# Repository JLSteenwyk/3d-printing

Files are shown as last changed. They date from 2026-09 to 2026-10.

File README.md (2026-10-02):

# 3D printing projects

Source models, printable exports, and build notes for projects printed on a
Bambu Lab P2S. Dimensions are in millimeters. Each project lives in its own
directory so materials, revisions, and instructions stay together.

| Project | Material | Status |
| --- | --- | --- |
| [01 — Olive Lantern](projects/01-olive-lantern/) | Bambu PETG Translucent, Olive | Prototype; physical fit and print validation pending |
| [02 — Organic Lantern TriLamp](projects/02-trilamp-desert-tan/) | PLA Matte, Desert Tan / grey-blue | Bowed shade, rounded cap, and source-based local full-set build |
| [03 — Narrow Flutes Tray Lamp](projects/03-narrow-flutes-tray-lamp/) | Translucent olive PETG / desert tan PLA trim | V2 one-piece body prototype; tray fit, socket adapter, slicing and heat tests pending |

Repository: https://github.com/JLSteenwyk/3d-printing

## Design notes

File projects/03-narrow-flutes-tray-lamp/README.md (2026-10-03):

# Narrow Flutes Tray Lamp — V2

A Bauhaus-inspired, translucent olive PETG lamp with a snug recessed receiver
for an unmodified Nordik leather valet tray. The olive body, tray ledge and lower
frame print as one connected part; desert tan PLA trim prints separately.
One horizontal Govee H6008 A19/E26 bulb is reserved inside the body.

**Mechanical prototype:** the socket adapter and strain relief are unfinished.
The R27 corner coupon and complete tray rim have been physically tested and
accepted by the user. Slicing, support-free printing, strength and heat behavior
still need validation. Socket mount and cord restraint remain unfinished.

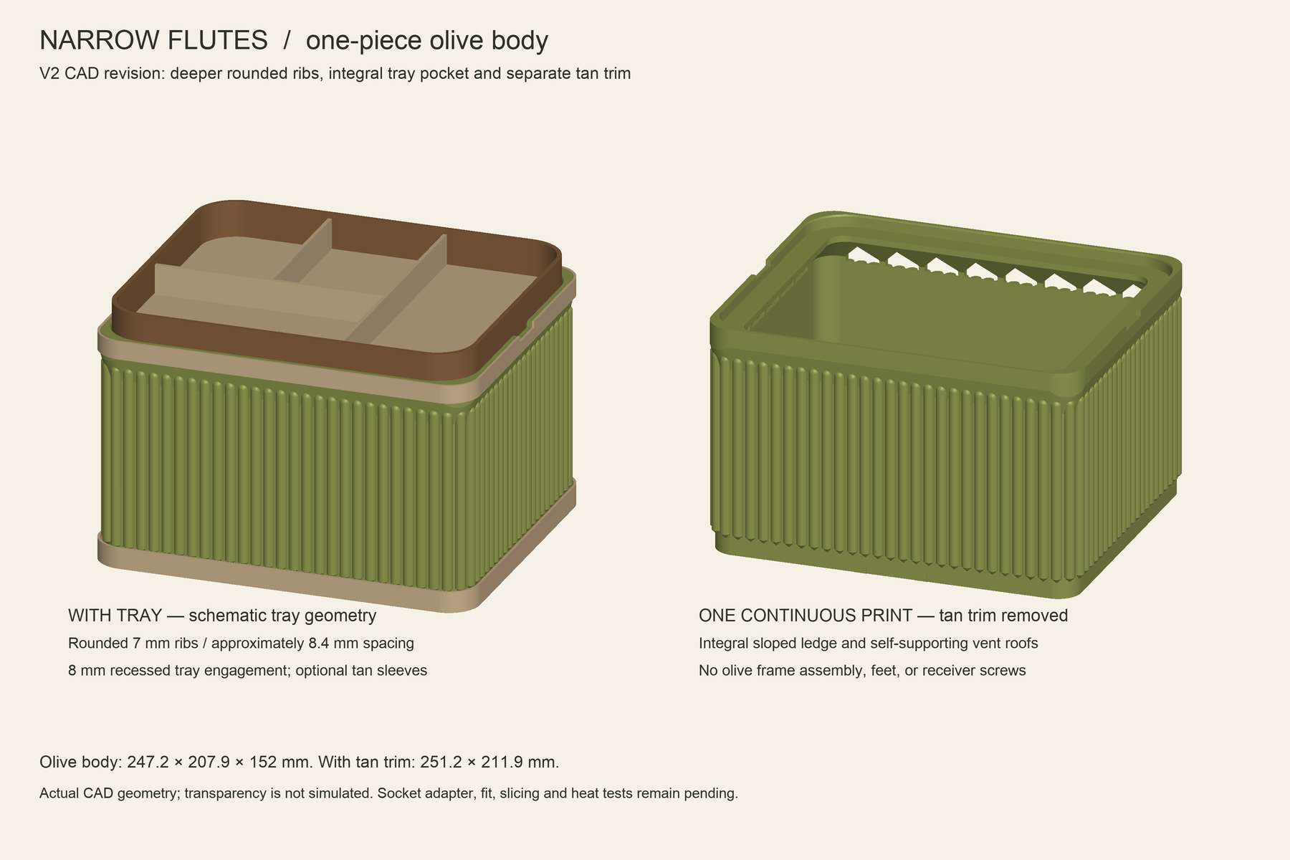
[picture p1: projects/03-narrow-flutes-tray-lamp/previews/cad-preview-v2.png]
Actual CAD geometry, with a schematic tray


## Downloads

| Part | Material | Purpose |
| --- | --- | --- |
| [Corner coupon](models/tray_corner_coupon.stl) | PETG | Accepted R27 corner shape; optional repeat check |
| [Complete fit-test rim](models/tray_fit_test_rim.stl) | PETG | Confirm full length, width and grip-pad fit |
| [One-piece olive body](models/olive_body_one_piece_PETG.stl) | Translucent olive PETG | Integral diffuser, frame and tray receiver |
| [Base trim](models/tan_base_trim_PLA.stl) | Desert tan PLA | Separate cosmetic sleeve |
| [Top trim](models/tan_top_trim_PLA.stl) | Desert tan PLA | Separate cosmetic sleeve |

STLs use millimeters and are placed flat/upright with minimum Z at zero.
The body uses ordinary printing mode, not vase mode. Sloped ledge supports and
45-degree vent roofs are intended to avoid trapped supports, but a connected
mesh is not proof of a successful support-free print. No verified P2S 3MF or
G-code is included.

## Dimensions and fit

| Feature | Dimension |
| --- | --- |
| Provided tray | 240.03 × 200.66 × 25.40 mm; 371.4 g before contents |
| Olive body | 247.23 × 207.86 × 152 mm |
| Footprint with tan trim | 251.23 × 211.86 mm |
| Tray pocket | 241.23 × 201.86 mm; 8 mm deep |
| Rigid clearance | 0.6 mm per side; adjustable compressible grip pads |
| Height with inserted tray | 169.4 mm |
| Rib profile | Rounded 7 mm-wide ribs, ~8.4 mm pitch, 3.4 mm relief |

The tray corner radius is **27 mm**, selected through a printed coupon fit test
and accepted on October 2, 2026. It is a fitted model value, not a direct radius
measurement. The exterior corner radius remains 18.6 mm, as on that coupon.
The complete rim and lamp now use this accepted pocket shape. The complete rim was also accepted by the user on October 2, 2026. The tray lifts out deliberately;
the receiver restricts sideways movement without a positive upward latch.

The 251.23 mm-wide trim leaves only about 2.38 mm per edge on the P2S's nominal
256 mm build area. Check plate placement and brim width in Bambu Studio.

## Regenerate

Tested with Python 3.12 and the versions in [requirements.txt](requirements.txt).
From this project directory:

```sh
python -m venv .venv
source .venv/bin/activate
python -m pip install -r requirements.txt
python src/generate.py
```

Edit [parameters.json](parameters.json) before regenerating. The script writes
the meshes to `models/`, validation to `docs/`, and the CAD preview to `previews/`.
Fonts fall back to a bundled Pillow font if Arial or DejaVu Sans is unavailable.
Some rib geometry, vent positions and mounting features remain fixed prototype
values in the source; review those when changing major dimensions.

To reproduce the optional geometric overhang screening (also regenerates the
models and preview):

```sh
python src/screen_overhang.py
```

## Validation and remaining work

[Mesh report](docs/validation.json): all five designs are single connected,
watertight, consistently wound solids within the nominal 256 mm build envelope.
Tan sleeves do not overlap the olive body. Reserved bulb/socket envelopes do not
intersect the body. Exported STL files were reloaded and checked for watertightness
and exactly two incident faces per edge.

[Overhang screening](docs/overhang-screen.json) compares 0.2 mm-spaced horizontal
sections with the prior section expanded by 0.25 mm. It identifies small local
overhangs; it is **not** toolpath generation or slicer validation.

Before the complete lamp is used:

1. Tray pocket fit is accepted; confirm any added grip pads before use.
2. Select a complete prewired E26 socket/cord assembly and design its adapter,
   retention and strain relief. The current 45 × 45 mm socket allowance is provisional.
3. Inspect and slice the full body in Bambu Studio; verify bridges and print settings.
4. Test the printed receiver with the tray and intended contents, then validate
   temperatures with the chosen bulb and the tray installed.

The H6008 label prohibits totally enclosed luminaires. V2 has intake and exhaust
windows on the rear and left end; acceptable temperatures have not been established.
This incomplete prototype should not be energized before hardware is finalized.

See [detailed design notes](docs/design-notes.txt) for mounting-pad geometry,
materials, fit tests and assembly limitations. The tray in the preview is schematic;
PETG transparency and glow are not simulated.

## References

- [Nordik tray](https://www.amazon.com/dp/B0C9CFWXQK)
- [Govee bulb](https://www.amazon.com/dp/B09B7NQT2K)
- [Manufacturer bulb label](https://fcc.report/FCC-ID/2AQA6-H6008/5384919.pdf)

This project was designed independently and does not include models from the
repository's TriLamp project.

## Socket fit test

The selected assembly is [Zarnicy B0D3TMJPWR](https://www.amazon.com/dp/B0D3TMJPWR).
The existing bulb/socket envelope check still uses the original provisional
45 mm socket allowance; it is not validation of the delivered Zarnicy socket.

Print [socket_hole_fit_gauge_37-41mm.stl](models/socket_hole_fit_gauge_37-41mm.stl)
flat in PETG at 100% scale. Five separate 3 mm thick rings are identified by
edge notches: 1 = 37 mm, 2 = 38 mm, 3 = 39 mm, 4 = 40 mm, 5 = 41 mm.
With the cord unplugged, choose the smallest ring that slides freely over the
external socket threads, then check that the original retaining ring clamps it
against the socket shoulder. Do not force or screw the printed gauge onto threads.
The final bracket depends on this fit result.

See [instructions](fit-revisions/socket/instructions.txt) and
[validation](fit-revisions/socket/validation.json). The generator writes the
gauge STL beside itself; copy it to models/ when regenerating.

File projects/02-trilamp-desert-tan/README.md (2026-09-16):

# TriLamp — Organic Lantern shade and matching cap

A softer replacement for the tall TriLamp shade: gently bowed sides, flowing
shallow waves, varied small openings, and a fine fuzzy finish. Designed for opaque
PLA in Desert Tan or other muted colors, including grey-blue.

**[Current design, cap download, and full-set build instructions](variants/organic-lantern/)**

## What is available here

- Our shade generator, cap design, stand extraction and project-building code.
- The independently designed matching cap, in printable STL and P2S 3MF formats.
- Previews and validation reports for the current design.
- Instructions for creating the full five-part set locally from the original file.

The original **TriLamp by XYZilla** is available on
[MakerWorld, model 772090](https://makerworld.com/en/models/772090).
Download the original stand files there; this public repository does not mirror
them. The source file identifies the Standard Digital File License, which
restricts redistribution of the original models and derivatives. Consequently,
source-derived shade meshes and the full-set 3MF are generated locally and
excluded from Git unless separate publication permission is obtained.

The three original tall-stand components are `TriLampStand.stl`,
`TriLampStand2.stl`, and `TriLampStand3.stl` (plate 6 of the supplied all-variants
project). The local build extracts them without changing their shape, preserving
the original print orientation.

[Previous Soft Spiral version](variants/soft-spiral/) remains available.

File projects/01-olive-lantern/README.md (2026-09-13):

# Olive Lantern

A mid-century modern floor-lamp sleeve: seven softly rounded sections, twelve
shallow vertical flutes, and a fine pebbled olive finish. The repeated forms
reference stacked ceramic lamps and paper lanterns. A removable, beveled saucer
cap finishes the top while leaving a central ventilation opening. Translucent PETG and fuzzy
skin should soften the LEDs; actual diffusion and color need a print trial.

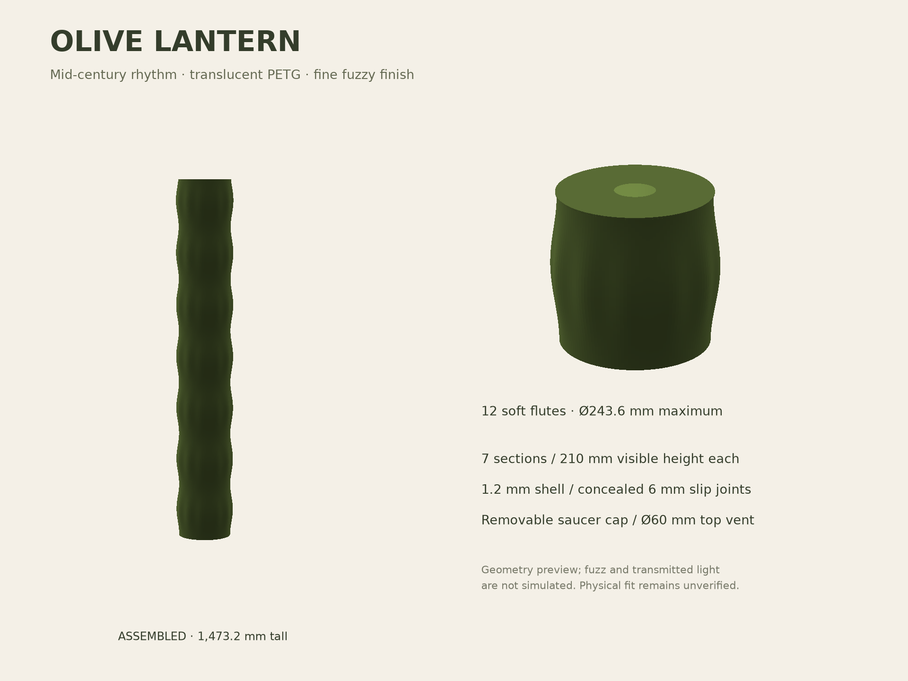
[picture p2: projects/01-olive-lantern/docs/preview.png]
Geometry preview


**Prototype status:** printable meshes are supplied, but physical fit, heat,
stability, and diffusion have not been tested. The full-height sleeve is the
initial design assumption; dimensions are based on the online sources below.

## Lamp and fit

The [linked Amazon listing](https://www.amazon.com/dp/B0BLSGHRXB?th=1) identifies
a Govee H6076 RGBIC floor lamp, with nominal dimensions 7.9 × 7.9 × 53.7 inches
(200.7 × 200.7 × 1364 mm). This is a freestanding sleeve around that lamp, with
its own bottom edge resting on the floor. There is no socket fitting, pole
clamp, or load on the LED column. Govee's [H6076 manual](https://m.media-amazon.com/images/I/B1zVyXg1UkL.pdf)
shows a cable leaving the base, followed by an inline controller and separate
power adapter. The rear arch admits the cable from below, so neither the
controller nor the adapter needs to pass through it. Their dimensions therefore
do not constrain the shade's diameter. The manual does not dimension the cable
exit or strain relief; the arch is a design allowance, not a measured fit.

An [H6076 product information sheet](https://maxelektro.pl/storage/file/pimcore_import/2023/10/6/c3b5da00f8b2dd766408e5ee16213a8f/lampa-led-govee-h6076-karta-informacyjna-produktu.pdf)
also reports 200 × 200 × 1410 mm. Rather than assume these listings describe
identical revisions, the shade covers the taller published envelope too, with
60 mm of headroom. For the exact linked 53.7-inch silver variant, headroom is
about 106 mm. Sources researched September 12, 2026.

| Dimension | Design |
| --- | --- |
| Assembled height | 1473.2 mm with cap; 1470 mm without |
| Maximum diameter | 243.6 mm, before fuzz |
| Visible section height | 210 mm |
| Base / middle print height | 216 mm, including collar |
| Top print height | 210 mm, no protruding collar |
| Separate cap | Ø224 × 9.2 mm in print orientation; adds 3.2 mm when seated |
| Cap vent / roof | Ø60 mm central opening / 1.6 mm roof |
| Shell thickness | 1.2 mm radial; approximately three extrusion lines |
| Bottom opening diameter | 217.6 mm |
| Minimum passage diameter, inside collars | 214.5 mm |
| Male collar outside diameter | 216.9 mm |
| Joint clearance | 0.70 mm diametral / 0.35 mm radial |
| Collar engagement | 6 mm |
| Rear cable arch | 10 mm high, approximately 21 mm wide at floor; 8 mm flat crown |

The 214.5 mm minimum passage gives approximately 6.9 mm radial clearance
around the linked nominal 200.7 mm base when centered. The shade is located
concentrically around that base, not around the off-center column. Use the short
fit ring to verify the as-printed clearance before making seven large parts.
Keep the inline controller and adapter outside the shade, with the flexible
cord laid through the open-bottom arch. If the cable exit prevents the bottom
rim from sitting flat, enlarge the arch parameter before printing the full set;
do not trap or sharply bend the cord.

## Files and print quantities

| STL | Quantity | Purpose |
| --- | --- | --- |
| [fit_male.stl](models/fit_male.stl) | 1 first | Short ring with the actual minimum bore and male collar |
| [fit_female.stl](models/fit_female.stl) | 1 first | Mating clearance check |
| [base.stl](models/base.stl) | 1 | Bottom section with rear cable arch |
| [middle.stl](models/middle.stl) | 5 | Repeated section with top collar |
| [top.stl](models/top.stl) | 1 | Uppermost shade section; receives the cap |
| [cap.stl](models/cap.stl) | 1 | Removable beveled lid with central vent |

Print the rings separately, upright, with no fuzz. Confirm that the female ring
seats on the male shoulder by hand without force and that the male ring clears
the lamp. These simplified rings test nominal joint diameters; the complete
base and one middle section are the next assembly test. Full-size female
openings flare slightly above their bottom edge.

The seven shells contain about 1.30 liters of plastic, roughly **1.7 kg of
PETG** using 1.27 g/cm³ as an estimate, before brims, calibration, and test rings.
Plan for two 1 kg spools; use the slicer's estimate for purchasing and scheduling.
The separate cap adds approximately 85 g before brim and slicer adjustments.

## Top cap

Print [cap.stl](models/cap.stl) **as supplied, broad exterior face on the plate
and locating collar pointing up**. Use the same PETG, 0.20 mm layers, 3 walls,
3 top/bottom layers, and a 3 mm brim. For this part use **100% infill** so the
1.6 mm roof is solid throughout. Supports and vase mode stay off. Its flat
annular face sits on the bed and the beveled edge narrows upward; there is no
large unsupported roof to bridge.

Keep fuzzy skin **off on the cap** for the first print. Its visible flat face
takes the build plate's finish; fuzzy skin does not texture this horizontal
face. A textured plate gives it a complementary texture. The locating collar
and seating annulus must remain smooth for fit.

After printing, flip it over and lower its collar into the existing top section.
It uses the same 0.35 mm radial clearance and 6 mm engagement as the test rings.
The cap is removable and needs no glue; it covers about 92% of the original
opening, leaving a Ø60 mm central vent (approximately 28 cm²). Keep that vent
clear. This opening is a ventilation provision, not verified thermal performance:
repeat the attended lighting trial with the cap fitted. Remove it if heat builds
up. The original upper shade section and other previously generated parts are
compatible without modification.

## Bambu Studio setup

These are proposed starting settings, not a physically qualified print profile.
STLs contain geometry only; they do not contain fuzzy skin or printer settings.

1. Select **Bambu Lab P2S, 0.4 mm nozzle**, and **Bambu PETG Translucent**. Use
   the filament profile's temperatures, cooling, and volumetric flow limit.
   The locally installed Studio 2.8.2.61 P2S preset specifies 250°C first layer,
   245°C subsequent layers, and 6 mm³/s maximum volumetric speed. Keep the
   selected plate's matching bed preset and prepare it for PETG. Dry the spool
   according to Bambu's current material instructions.
2. Begin with 0.20 mm layers, **3 wall loops**, **0% sparse infill**, and 3 top /
   bottom shell layers. The modeled center stays open; top and bottom layers
   only close the thin material rims and shoulder. Keep vase mode **off**.
   Use Arachne wall generation if the fixed-width preview leaves shell gaps.
3. Place **one section per plate**, upright as supplied, at 100% scale. Use a
   3 mm outer brim, supports off, outer wall speed around 40 mm/s, and align
   the seam toward the rear cable opening. Inspect the cable arch's short crown
   bridge on the base trial. Enable neither a prime tower nor smooth timelapse
   features that reserve space or cause unnecessary travel.
4. Set **Fuzzy skin: Contour**, thickness **0.15 mm**, point distance **0.40 mm**.
   Keep **Z=0–14 mm and Z=204 mm to the part top smooth** using height-range
   settings with fuzzy skin disabled. Alternatively paint only the outside
   between those heights in Studio's fuzzy-skin painting tool. The upper smooth
   range includes the collar and shoulder. The bottom smooth range preserves
   the cable arch, first layers, and receiving rim. Use no fuzz on either test
   ring. Inspect the sliced preview to confirm that the inner walls and mating
   surfaces are smooth, especially around the arch.
5. Inspect all layers for a continuous shell, preserved collar, open center,
   and plate clearance before sending a job. A nominal 3 mm brim plus 0.15 mm
   fuzz stays within a 256 mm square, but the selected printer's exclusions,
   purge lines, and slicer placement still need checking.

Print the base first to assess the actual material's light transmission and
texture before making the other six pieces. Fuzzy skin scatters light and may
make the olive look more opaque. Try a warm white lamp setting first; tinted
plastic will alter the apparent RGB colors. For a coarser finish, trial 0.20 mm
thickness and 0.50 mm point spacing on a small sample before changing the set.

## Assembly

Turn off and unplug the lamp. Lower the base section over the column and seat
it on a hard, level floor around the lamp base, with the cable arch at the rear.
Route the cord through the arch without pinching; reconnect only once clearance
is checked. Lower the five middle sections individually over the column, then
the top section. Each receiving rim rests on the previous shoulder; rotate the
flutes and rear seams into alignment. Flip the separately printed cap collar-down
and seat it in the top section; leave the central vent unobstructed.

The slip joints locate the sections but **do not lock them together**. Check
the stack for rocking and use removable clear tape bridging the outside of
each joint for the initial trial. Keep it where it cannot be bumped, and move
it by dismantling it, not by lifting the top. A narrow, tall freestanding shade
needs an actual stability check before regular use; if the intended location
is exposed to knocks, add a measured base restraint before installing it there.

For the first lighting trial, run the actual LED lamp at its brightest intended
setting while attended. Confirm there is an air gap around the column, the cord
is free, and the shade does not soften, distort, or develop a hot spot as it
warms up. PETG temperature resistance is not proof that this assembly is safe.
This design is for the linked LED column, not incandescent or halogen lamps.

## Regeneration and validation

From the repository root:

```bash
python3 projects/01-olive-lantern/src/generate.py
# Optional geometry illustration; requires numpy and matplotlib:
python3 projects/01-olive-lantern/src/preview.py
```

Edit `Parameters` in [src/generate.py](src/generate.py) to change the neck,
wall, flutes, or clearances, then regenerate all parts together. Dimensions in
this README describe the defaults. The height / vertical-step ratio is
constrained to 2 mm to retain the modeled collar taper. Changing the number of
sections affects the preview and required quantity, not the individual STL.

The generator checks nondegenerate triangles, two faces per edge, consistent
winding, positive enclosed material volume, and nominal P2S bounds. Results
are in [docs/mesh-report.json](docs/mesh-report.json). The slicer trial and its
limitations are in [docs/validation.md](docs/validation.md). These checks do not prove
physical fit, stability, thermal performance, or successful printing.

## References

- [Lamp listing](https://www.amazon.com/dp/B0BLSGHRXB?th=1): lamp identification and nominal envelope.
- [Govee H6076](https://us.govee.com/products/govee-rgbicw-smart-corner-floor-lamp): manufacturer's lamp page.
- [P2S manufacturer announcement](https://blog.bambulab.com/the-icon-redefined-meet-the-p2s-a-completely-reengineered-version-of-the-ultra-productive-p1-series/): 256 × 256 × 256 mm build volume.
- [Bambu PETG Translucent](https://us.store.bambulab.com/products/petg-translucent?id=42479468281992): translucent material and Olive color, #748C45.
- Bambu Studio 2.8.2.61 installed BBL profiles: P2S 0.4 mm PETG Translucent temperature and flow settings. The fuzzy values above are design recommendations.

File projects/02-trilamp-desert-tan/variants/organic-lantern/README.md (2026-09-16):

# Organic Lantern — bowed shade and rounded cap

[Color preview](previews/colors.png) · [Cap STL](models/cap.stl) ·
[Cap 3MF](studio/TriLamp_Organic_Lantern_Cap_P2S.3mf)

A warmer revision of Soft Spiral with a fuller middle, gently wandering shallow
waves, and staggered rounded slits of varying lengths. Fine external fuzzy skin
is enabled at 0.12 mm thickness / 0.4 mm point distance, with the fitting bands
kept smooth. Desert Tan and muted grey-blue use the same geometry; the blue
preview is illustrative rather than a matched filament swatch.

## Geometry

- Shade height: 210 mm; unchanged 85 mm end diameter.
- Middle: approximately 95 mm diameter, with a subtle asymmetric contour.
- Wave depth reduced from 0.8 to 0.45 mm; spacing increased from 5.2 to 7 mm.
- 936 rounded slits, nominally 4.6–5.6 mm long and 2.25 mm high before
  tilting to follow the waves, with continuous gently arched roofs.
- Approximate projected opening area: 9,488 mm² versus 9,420 mm² previously.
  This preserves aperture area, not a measured light-output guarantee. Opaque
  filament sends light through the openings; it will not glow like translucent PLA.
- Original keyed mounting geometry retained; both end interfaces remain fixed.
- Removable cap: 85 mm diameter, rounded 1 mm edge radius, 2 mm roof, 4 mm
  locating ring, and twelve curved vents. The previous Soft Spiral cap also fits.

The previews render the actual assembled meshes. Fuzzy skin is applied during
slicing and is not shown in these previews. Physical fit and illumination have
not been tested on a printed prototype.

## Local printable files

The build creates shade-only Desert Tan and grey-blue projects, a cap project,
a three-part original stand project, and a full five-part project on two plates.
Plate 1 holds the shade and cap; plate 2 holds the original tall stand parts.
Projects use Bambu P2S / 0.4 mm nozzle / PLA Matte / 0.2 mm layers / Textured PEI,
with supports disabled. Cap prints exterior face down and locating ring up;
flip it to install. Change the filament preset when using a different material.

## Build from the original

Obtain the original all-variants 3MF from
[TriLamp by XYZilla on MakerWorld](https://makerworld.com/en/models/772090).
The original file's Standard Digital File License restricts redistribution.
Original stands and meshes containing the original mount stay local; this
repository publishes our code, independent cap, and previews.

From the repository root on macOS with Bambu Studio installed:

```sh
python3 -m venv .venv
.venv/bin/pip install numpy trimesh manifold3d scipy networkx shapely matplotlib
.venv/bin/python projects/02-trilamp-desert-tan/variants/organic-lantern/src/build_all.py '/path/to/TriLamp-AllVariants(4).3mf'
```

The build validates the mesh, compares the retained mount against the original,
checks cap interference, exports native Bambu Studio projects, and slices the
complete set. It reports slicer warnings if any occur. Files are written to
this variant's `models/` and `studio/` directories. Use `--studio` to specify
another Bambu Studio executable path.

## Validation of this revision

Both plates sliced successfully in Bambu Studio 2.08.02.61 with supports off
and no plate warnings. Shade + cap: approximately **105 g / 8 h 37 min**.
The complete set including the three original stand parts: approximately
**164 g / 12 h 8 min**. These are slicer estimates, not measured print times.
Meshes are closed solids, the retained mount matches within export precision,
and the cap has no modeled interference with the shade.

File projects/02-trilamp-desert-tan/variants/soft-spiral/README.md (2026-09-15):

# Soft Spiral — tall shade, matching cap, and full local set

[Cap 3MF](studio/TriLamp_Soft_Spiral_Cap_P2S.3mf) ·
[Cap STL](models/cap.stl) · [Cap preview](previews/cap.png) ·
[Shade color preview](previews/colors.png)

Soft Spiral uses rounded horizontal folds and small capsule openings in their
valleys, with fine fuzzy skin for a softer finish. Desert Tan and the illustrative
muted grey-blue preview use the same geometry. The inner keyed mounting recess
is retained from the supplied tall TriLamp shade.

## Complete set

| Part | Availability |
| --- | --- |
| Soft Spiral shade | Generate locally using the original 3MF |
| Matching vented cap | Printable files linked above |
| Original tall stand, `TriLampStand.stl` | Obtain from XYZilla; extracted by the local build |
| Original stand base, `TriLampStand2.stl` | Obtain from XYZilla; extracted by the local build |
| Original collar, `TriLampStand3.stl` | Obtain from XYZilla; extracted by the local build |

The full local project has two plates: shade + cap, then the three stand parts.
All use P2S / standard 0.4 mm nozzle / PLA Matte / Textured PEI settings. The
stand geometry is unmodified; its base is flipped to match the original profile's
printing orientation. Change the stand material preset if printing it in PETG.

### Matching cap

A removable drop-in cap, independently designed for the final Soft Spiral shade:
85 mm maximum diameter, a 2 mm roof, and a 4 mm locating ring. The ring has
approximately **0.34 mm minimum radial clearance** and a tapered entry. Twelve
rounded concentric vents match the softer surface treatment. The cap is retained
by gravity, not a latch. Print exterior face down, then flip to install.

Fuzzy skin is limited to the short roof perimeter; the locating ring stays smooth.
It adds 2 mm to the assembled shade height. Geometry checks find no interference
with the shade. **Cap estimate: 15 g / 42 min.**

### Shade and colors

210 mm tall × 85 mm maximum diameter; 1.2 mm radial body wall. Spiral pitch is
5.2 mm, with 0.8 mm crest-to-valley relief. The 1,120 small openings are
5.6 × 1.6 mm, with rounded ends and offsets between turns. The repeating pattern
has approximately 20% projected open area; light passes through these openings
in opaque filament. Actual light output has not been measured.

Desert Tan display color is #E8DBB7. Grey-blue is **illustrative #6F8491**, not a
matched Bambu swatch. Both generated color files use PLA Matte settings; choose
your actual filament profile, especially for PETG or another material.

## Build the full set locally

Download the original all-variants project from
[XYZilla's TriLamp page](https://makerworld.com/en/models/772090).
The tested input is `TriLamp-AllVariants(4).3mf`, with the tall stand on plate 6.
Bambu Studio must be installed. The scripts currently resolve presets from its
standard macOS application path.

From this repository's root:

```bash
python3 -m venv .venv
.venv/bin/pip install numpy trimesh manifold3d scipy networkx shapely matplotlib
.venv/bin/python projects/02-trilamp-desert-tan/variants/soft-spiral/src/build_all.py '/path/to/TriLamp-AllVariants(4).3mf'
```

The build generates and validates these local files under this folder's `studio/`:

- `TriLamp_Soft_Spiral_Desert_Tan_P2S.3mf`
- `TriLamp_Soft_Spiral_Grey_Blue_PLA_P2S.3mf`
- `TriLamp_Soft_Spiral_Cap_P2S.3mf`
- `TriLamp_Original_Tall_Stands_P2S.3mf`
- `TriLamp_Soft_Spiral_Full_Set_P2S.3mf`

For just the independent cap, run `src/complete_set.py` without a source argument.
The cap does not require the original file. To regenerate pictures, run
`src/preview.py` and `src/preview_cap.py` after generating the meshes.

## Printing and validation

0.20 mm layers, three walls, Arachne, 15% infill, five top/bottom layers, supports
off, vase mode off, 4 mm outer brim. Outer walls 35 mm/s, inner walls 60 mm/s,
bridges 25 mm/s. PLA nozzle temperature 220 °C.

Shade fuzzy skin: External, 0.12 mm thickness / 0.40 mm point distance, Z 14–203 mm.
Cap fuzzy skin: Z 0–1.8 mm. The stand parts have fuzzy skin off. Global fuzzy skin
is None because object height ranges control it. Open a 3MF as a project to retain
these settings, then slice before printing.

The two-plate set sliced in Bambu Studio 2.08.02.61 with return code 0, supports
off, and no plate warnings. **Full-set estimate: 159 g / 11 h 52 min.**
Physical fit, print finish, and operating temperature remain untested. Use the
original LED-001 setup and keep cap vents clear.

[Cap geometry checks](cap-validation.json) ·
[Cap slicing results](cap-slice-validation.json) ·
[Full-set slicing results](full-set-slice-validation.json)

## Publication and attribution

Original **TriLamp by XYZilla**, MakerWorld model 772090. The supplied 3MF identifies
its Standard Digital File License. The original stand meshes, source-derived shade
meshes, and full-set 3MF are not mirrored in this public repository; obtain separate
permission before redistributing them. Git ignores those local generated files.
Our code, independently designed cap, previews, and reports are included here.

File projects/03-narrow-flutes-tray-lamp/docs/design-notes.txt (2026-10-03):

NARROW FLUTES V2 — SINGLE OLIVE PRINT, SEPARATE TAN TRIM

V2 changes
The olive wall, lower frame, socket-adapter pad, supporting ledge and recessed
tray receiver are one connected PETG model. There are no olive assembly joints,
separate feet, or screws between the diffuser and receiver. The tan base and
top sleeves print separately and slip on afterward, with removable adhesive
tabs if needed. The socket, its adapter, cord and grip pads install afterward.

Appearance
V1's ribs were only 1.6 mm deep and looked like shallow corrugations. V2 uses
rounded 7 mm-wide ribs with 3.4 mm relief and approximately 8.4 mm spacing.
Their upper ends are rounded; lower 45-degree chamfers are hidden by tan trim.
The front and right faces are uninterrupted. Intake and exhaust windows are
on the rear and left end. The continuous ventilation gap of V1 is removed.
This model follows the selected concept's round rib texture; it cannot promise
the AI image's exact glow or unmeasured proportions. The preview renders actual
CAD geometry with a schematic tray. It does not simulate PETG transparency.

Dimensions
Olive body: 247.23 x 207.86 x 152 mm. With tan trim: 251.23 x 211.86 mm.
Tray pocket: 241.23 x 201.86 mm, 8 mm deep, 0.6 mm rigid clearance per side.
Tray sits at 144 mm; total height with the supplied 25.4 mm tray is 169.4 mm.
Tray corner radius is fitted at 27 mm. User accepted the printed R27 coupon
on October 2, 2026. Pocket radius is 27.6 mm; exterior radius remains 18.6 mm.
Full R27 rim fit was also accepted by the user on October 2, 2026. This is not a direct radius measurement.
Grip pads: four 24 x 4.5 mm recesses, 0.3 mm deep. Start with compressible
adhesive pads near 1 mm thick and adjust according to actual fit.
The tray is retained against lateral motion, but is deliberately lift-out.
Tan sleeves have 0.3 mm radial slip clearance around the olive receiver/body.
They are cosmetic and do not replace the PETG load-bearing structure.

Printing intent
Print olive_body_one_piece_PETG.stl upright, flat base on the bed, using ordinary
mode, not vase mode. It is designed to avoid long internal bridges: the ledge
grows inward over a 16 mm slope; vent and cord-opening roofs close at 45 degrees.
The base rails begin on the bed. The bulb can be installed and replaced through
the large tray opening. No permanently trapped printed supports are intended.
The remaining small transitions still need inspection in Bambu Studio. No
P2S toolpath, support setting or physical print has been validated. One connected
solid does not by itself prove successful support-free printing.
Tan trim fits the nominal 256 mm build volume but is 251.23 mm wide, leaving
only about 2.38 mm per edge. Inspect brim/plate placement carefully.
Use your PETG filament profile and test adhesion before the large body print.

First print
The R27 corner coupon and full tray_fit_test_rim.stl are accepted.
Next is the socket mounting-hole gauge and final hardware bracket. The fit samples reproduce the
V2 receiver geometry. Adjust parameters.json and regenerate before printing
the full lamp if the bare rim binds. Add pads after confirming the rigid fit.

Socket and thermal status
One horizontal A19 bulb envelope (123 x 60 mm), with a provisional 45 x 45 mm
socket envelope beside it, clears the model. This is a space reservation, not
the actual hardware. The socket mount/adapter and strain relief remain to be
designed around a selected complete prewired E26 socket-and-cord assembly.
The integral mounting pad has four 3.4 mm holes on a 40 x 24 mm pattern.
No printed electrical contacts are supplied. Do not energize this incomplete
prototype. Final hardware retention, access and cord routing need review.
There are 14 upper vent windows and 14 lower windows; tan trim does not seal
them. Adequate temperatures with the leather tray installed are not established.
The H6008 label prohibits use in totally enclosed luminaires. Final heat and
load/creep testing with the intended contents are still required.

Verification
All five exported designs are one connected, watertight, consistently wound
solid. They fit the nominal 256 mm build envelope. Tan trim has no material
overlap with the olive body; the reserved hardware envelope has no intersection.
overhang-screen.json records geometric layer-growth screening at 0.2 mm pitch;
this is not slicing or proof that supports are unnecessary. validation.json
records model checks and explicitly marks unfinished physical/slicer tests.

Editing
generate.py is the parametric CAD source; parameters.json holds tray dimensions,
clearance and main dimensions. Dependencies: numpy, manifold3d, trimesh, Pillow.
Run python generate.py. Some rib geometry, vent positions, socket pad and ledge
features are fixed prototype values in the source; review those after changing
parameters. The published project contains V2 with the accepted R27 receiver revision.

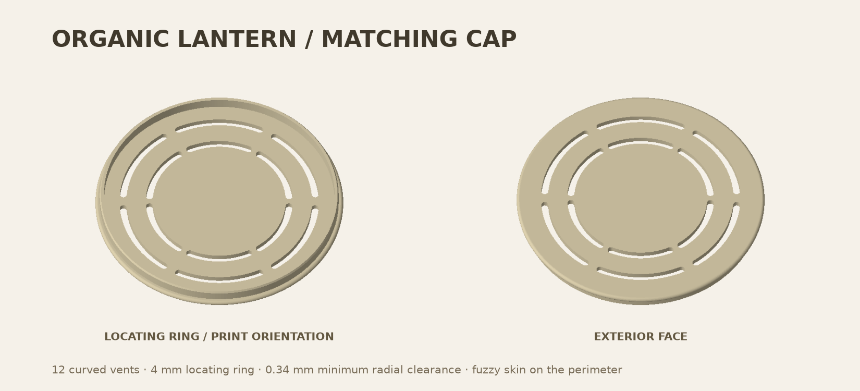
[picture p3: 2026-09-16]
projects/02-trilamp-desert-tan/variants/organic-lantern/previews/cap.png

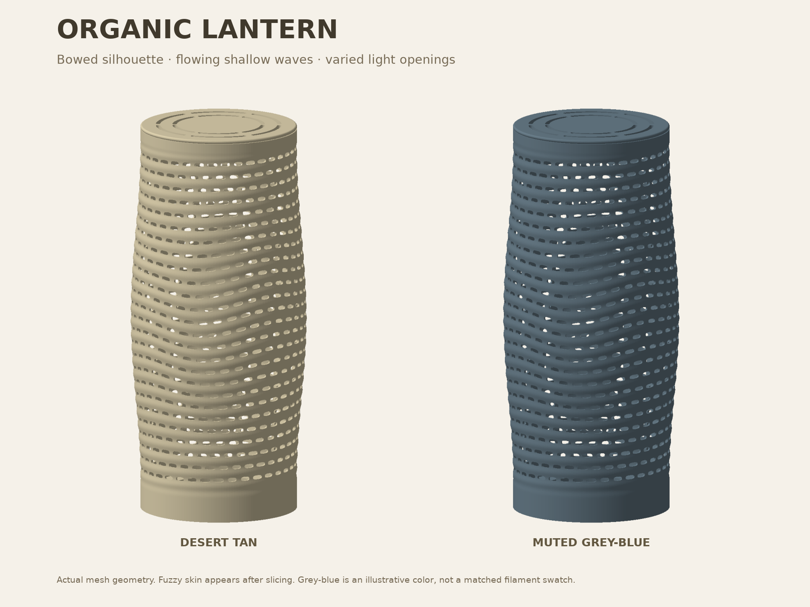
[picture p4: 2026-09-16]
projects/02-trilamp-desert-tan/variants/organic-lantern/previews/colors.png

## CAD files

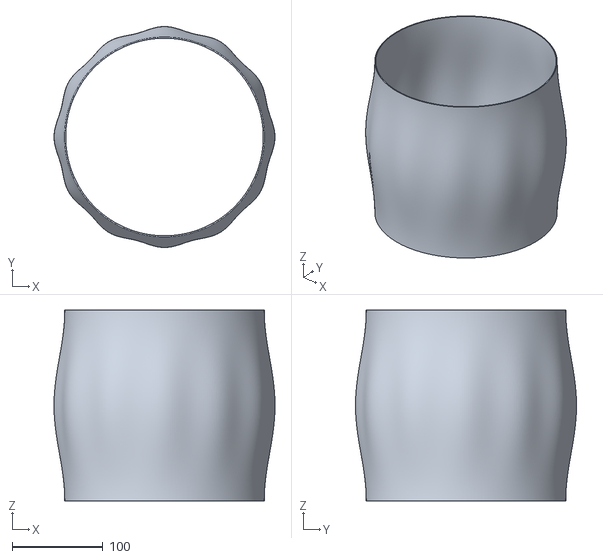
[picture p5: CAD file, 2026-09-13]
projects/01-olive-lantern/models/top.stl
243.6 x 243.6 x 210.0

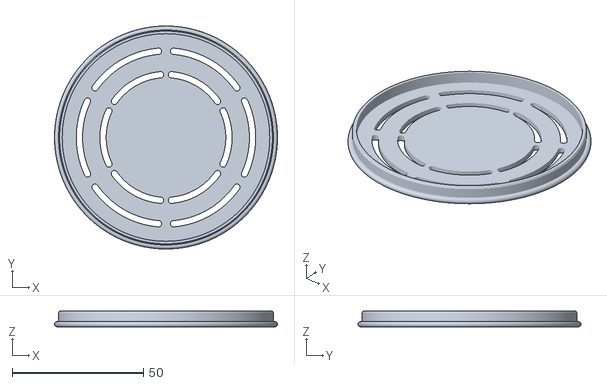
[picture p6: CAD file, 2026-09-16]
projects/02-trilamp-desert-tan/variants/organic-lantern/models/cap.stl
85.0 x 85.0 x 6.00

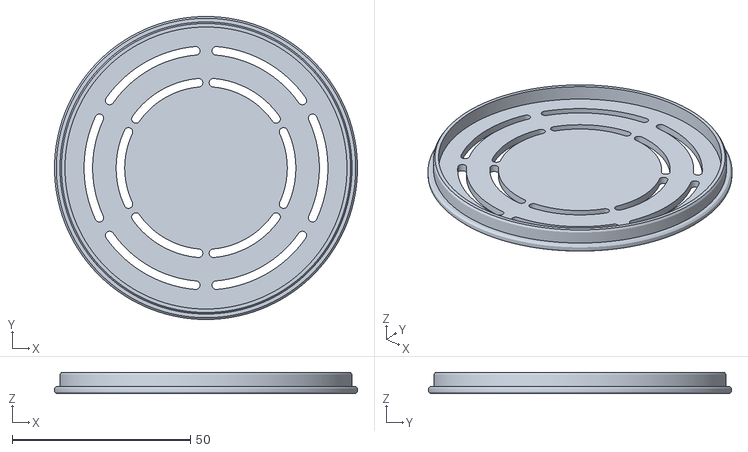
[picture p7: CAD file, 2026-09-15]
projects/02-trilamp-desert-tan/variants/soft-spiral/models/cap.stl
85.0 x 85.0 x 6.00

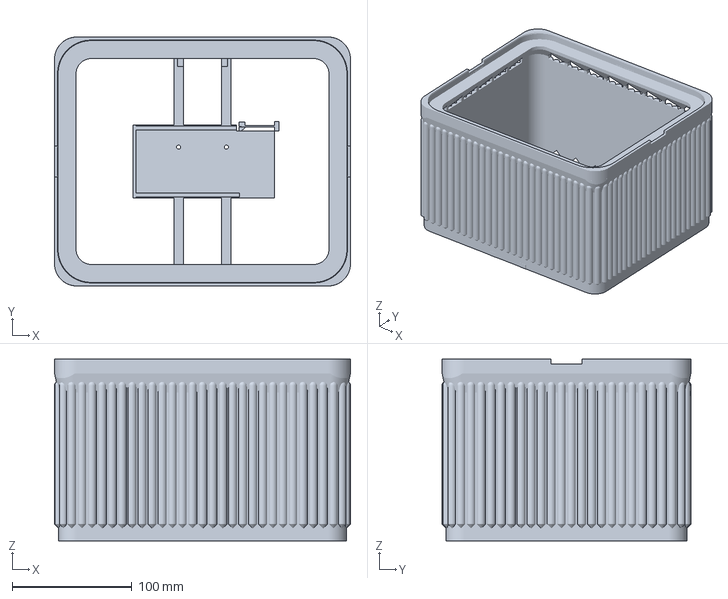
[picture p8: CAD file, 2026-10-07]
projects/03-narrow-flutes-tray-lamp/fit-revisions/slide-mount-v3/models/olive_body_slide_mount_PETG_Bambu_project.3mf
247.2 x 207.9 x 152.0 mm

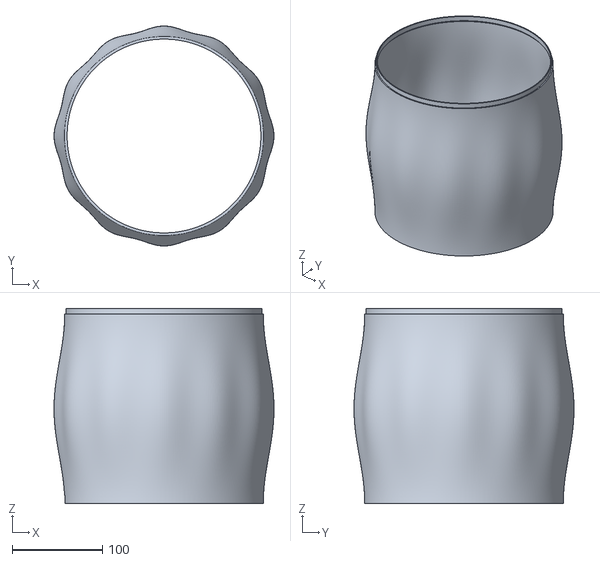
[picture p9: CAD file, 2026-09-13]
projects/01-olive-lantern/models/base.stl
243.6 x 243.6 x 216.0

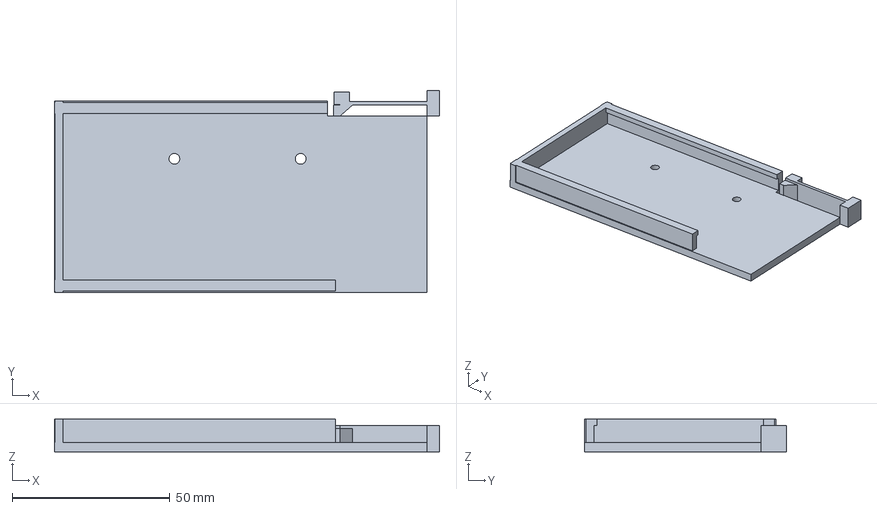
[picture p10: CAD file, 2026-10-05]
projects/03-narrow-flutes-tray-lamp/models/slide_receiver_test_v2_PETG.3mf
122.0 x 63.9 x 10.4 mm

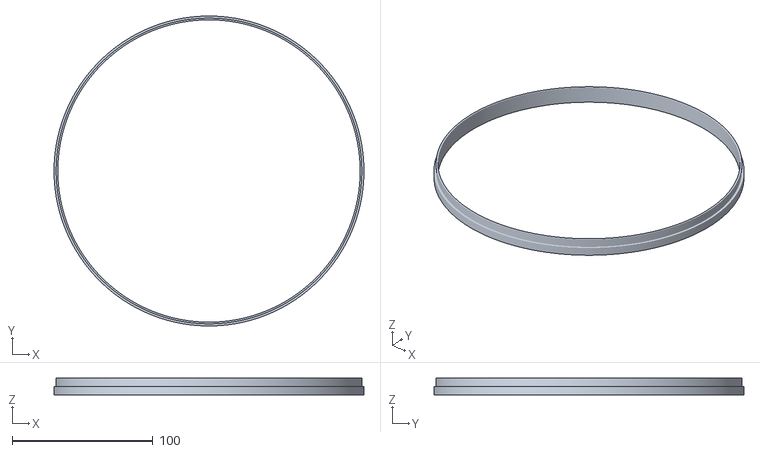
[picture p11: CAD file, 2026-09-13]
projects/01-olive-lantern/models/fit_male.stl
220.0 x 220.0 x 12.0

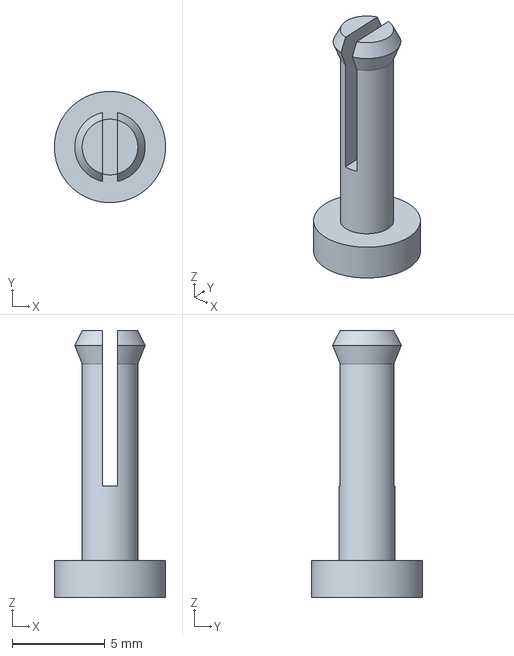
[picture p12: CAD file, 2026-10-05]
projects/03-narrow-flutes-tray-lamp/models/anchor_snap_pin_PETG_print_two.3mf
6.00 x 6.00 x 14.4 mm

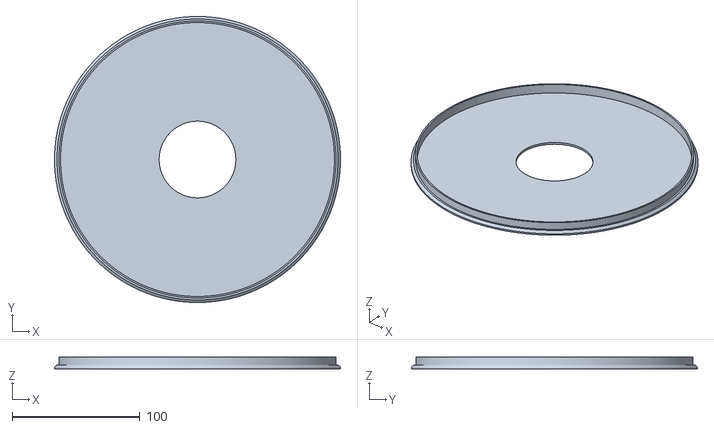
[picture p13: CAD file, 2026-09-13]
projects/01-olive-lantern/models/cap.stl
224.0 x 224.0 x 9.20

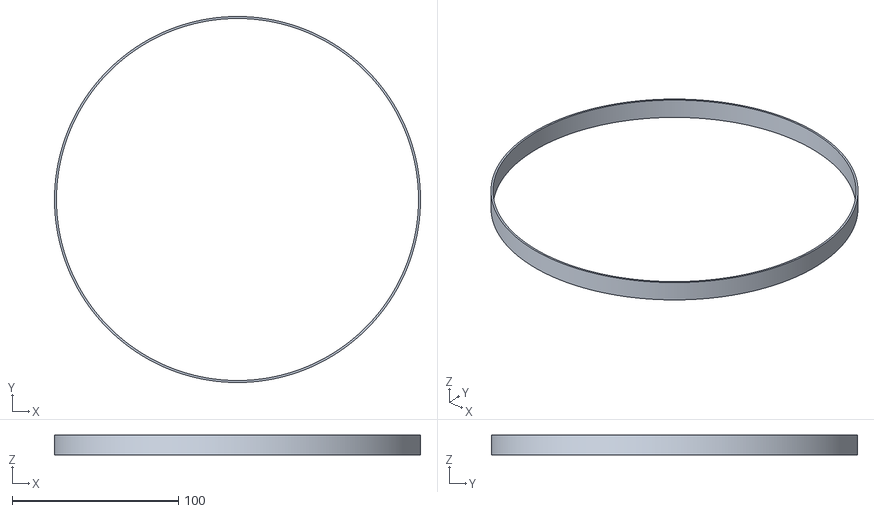
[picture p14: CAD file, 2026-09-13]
projects/01-olive-lantern/models/fit_female.stl
220.0 x 220.0 x 12.0

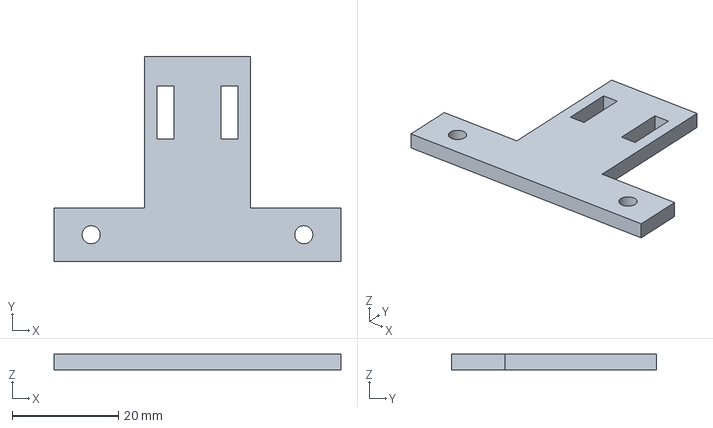
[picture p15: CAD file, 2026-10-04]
projects/03-narrow-flutes-tray-lamp/models/cord_anchor_plate_PETG.3mf
54.0 x 38.5 x 3.00 mm

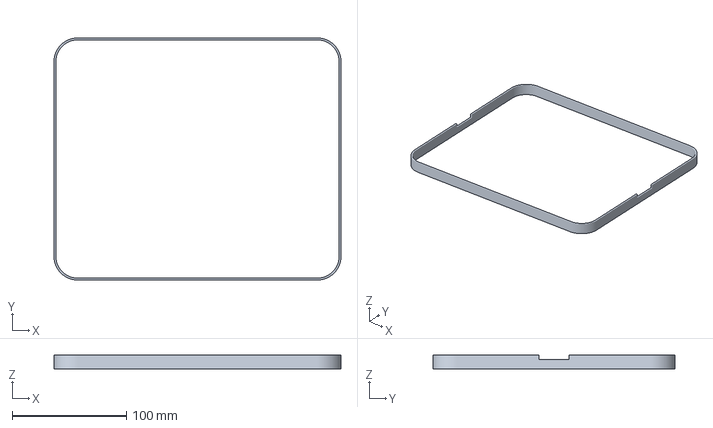
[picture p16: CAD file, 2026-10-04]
projects/03-narrow-flutes-tray-lamp/models/tan_top_trim_PLA.3mf
251.2 x 211.9 x 12.0 mm

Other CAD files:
projects/02-trilamp-desert-tan/variants/organic-lantern/studio/TriLamp_Organic_Lantern_Cap_P2S.3mf
projects/02-trilamp-desert-tan/variants/soft-spiral/studio/TriLamp_Soft_Spiral_Cap_P2S.3mf
projects/03-narrow-flutes-tray-lamp/fit-revisions/slide-mount-v3/models/olive_body_slide_mount_PETG.3mf
projects/03-narrow-flutes-tray-lamp/models/olive_body_slide_mount_PETG.3mf
projects/01-olive-lantern/models/middle.stl
projects/03-narrow-flutes-tray-lamp/fit-revisions/slide-mount-v3/models/olive_body_slide_mount_PETG.stl
projects/03-narrow-flutes-tray-lamp/models/anchor_snap_pin_PETG_print_two.stl
projects/03-narrow-flutes-tray-lamp/models/cord_anchor_plate_PETG.stl
projects/03-narrow-flutes-tray-lamp/models/olive_body_one_piece_PETG.3mf
projects/03-narrow-flutes-tray-lamp/models/olive_body_one_piece_PETG.stl
projects/03-narrow-flutes-tray-lamp/models/olive_body_slide_mount_PETG.stl
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

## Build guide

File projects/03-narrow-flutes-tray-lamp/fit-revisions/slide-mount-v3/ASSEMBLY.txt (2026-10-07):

V3 lamp body with integrated slide receiver — prototype

Print olive_body_slide_mount_PETG.3mf upright in olive PETG. This is a geometry-only 3MF: select your printer, PETG profile and slicing settings in Bambu Studio. Inspect the sliced rail lips, latch gaps, vent roofs, and bridges before printing. Bambu Studio import/slicing has not been verified here.

Reuse the accepted socket bracket, cord anchor plate and two snap pins. The standalone V2 slide receiver is replaced by the receiver inside this body. Existing tan trims remain compatible.

With the cord unplugged and bulb removed, lower the bracket into the open top. Slide its base from the right-hand opening toward the closed stop on the left. Hold the latch outward if needed, then let it return behind the bracket's front edge. Verify that the bracket seats flat and cannot slide back out with the latch engaged.

Install the cord anchor and two snap pins as in the accepted test assembly. Route the cord with slack behind the socket and secure it through the anchor slots without crushing the jacket. Confirm that the pin tips clear the table and cord pulls do not move the socket. Screw in the bulb only after the bracket is seated.

The integrated receiver floor is raised 2 mm for snap-pin clearance. Its latch extends down to the print bed, increasing its height by 2 mm compared with the tested standalone receiver. Its stiffness and release action need physical confirmation. Stop if the latch cannot release easily; do not force the bracket.

CAD checks passed: body is watertight and one connected part; bracket seated and slide path clear rigid body geometry; conservative bulb/socket envelopes clear body. These checks do not establish print quality, electrical safety, or thermal performance. Final powered use awaits cord-retention and supervised heat checks. Keep ventilation openings clear.

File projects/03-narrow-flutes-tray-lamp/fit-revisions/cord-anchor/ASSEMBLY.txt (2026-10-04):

Keep the physically accepted socket bracket V1. The cord anchor is an optional separately printed addition sharing its two rear bolt holes (X +/-20, Y+12).

Print cord_anchor_plate_PETG.3mf flat in PETG at 100% scale. It is 3 mm thick and intended to need no supports. All provided 3MF files contain geometry and millimeter units, not Bambu printer or filament settings. Studio import and slicing have not been verified.

Put anchor on TOP of bracket base, tongue extending toward the lamp rear (+Y). Mount bracket to existing lamp pad with four M3 bolts, washers and nuts. Starting lengths: front M3 x16 mm; rear with anchor M3 x20 mm. Verify engagement and clearance on actual parts; do not overtighten PETG. Access nuts through open underside.

Route the cord toward the rear opening along the bottom, avoiding the bulb. Leave relaxed slack at the factory socket grip. Thread one 2.5 mm wide cable tie down one slot and up the other, wrapping it over the cord. Tighten only enough to hold the cable without flattening or marking its insulation. An adjustable tie anchor is not yet a proven strain relief: test unplugged with a gentle external tug to confirm no motion at socket and no insulation damage. Revise if it slips; do not crush the cable. Cord width/thickness confirmation remains pending.

Next print is the small anchor plate. Confirm slots/cord routing and hardware before committing to the large body print. Socket bracket fit and full tray fit are physically confirmed. Body, load/creep, cord restraint and heat behavior are not.

Full lamp files are olive_body_one_piece_PETG.3mf, tan_base_trim_PLA.3mf and tan_top_trim_PLA.3mf. Print olive body upright, ordinary mode, inspect corbel corners/bridges/vent roofs and brim placement in Studio. Print tan sleeves separately in PLA. Tan trim footprint is 251.23 x211.86 mm, leaving little brim room on nominal256 mm plate.

Do not energize the assembled prototype before cord retention and hardware are confirmed. Final temperature validation must use the intended bulb and installed tray; ventilation alone is not proof of acceptable temperatures.

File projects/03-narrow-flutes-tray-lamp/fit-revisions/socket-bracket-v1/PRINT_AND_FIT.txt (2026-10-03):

Socket bracket V1 — unpowered fit prototype

Print socket_bracket_40mm_PETG.stl upright on its broad base, PETG, 100% scale. Use supports beneath the horizontal ring overhang and inspect the 40 mm hole bridge in Bambu Studio. Remove supports fully. The small gauge was support-free; this taller bracket is not.

With the cord unplugged, remove the original retaining ring. Slide the socket through the 40 mm mounting hole from the gusset-free/back side, until its shoulder meets the plate. Reinstall the original retaining ring on the bulb side. Hand tighten. Confirm no rocking, shoulder interference or damaged threads. The hole and clamping plate match the accepted 40 mm / 3 mm gauge.

Insert the Govee bulb while unplugged. Check the socket cord grip, bulb and cord clear the base and webs. Confirm the bracket stays stable while gently installing/removing the bulb. Send a side photo of the assembled bracket with bulb before printing the lamp body.

Final assembly uses four M3 bolts and nuts through the existing 40 x 24 mm pad pattern. Bracket base thickness 5 mm plus lamp pad 5 mm: M3 x 16 mm is a starting length with washers/nuts, verify actual hardware. Install from the open underside. Hardware is not included.

Lamp assembly: bracket base bottom sits on pad at Z5; mounting face X-50, bulb axis Z75. Base holes align with existing pad. This STL is shifted to Z0 for printing; mount it on the pad without changing its orientation.

Cord routes behind the socket down to the rear opening. Keep cord slack away from the bulb. Cord thickness is not established; do not clamp or pinch insulation. Separate cord restraint still needs finalizing before power-up. This bracket fit test is not thermal or electrical validation. Do not energize the prototype yet.

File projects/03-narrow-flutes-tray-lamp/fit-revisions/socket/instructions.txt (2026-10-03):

Print flat in PETG at 100% scale, using the intended bracket print settings.
One STL contains five separate 3 mm thick test rings.
1 notch = 37 mm hole; 2 = 38; 3 = 39; 4 = 40; 5 = 41.
With the cord unplugged, remove its retaining ring and slide each test ring over the OUTSIDE socket threads. Do not insert a test ring into the electrical opening.
Choose the smallest hole that slides on freely without threading or force. Screw the original retaining ring back on and check that it clamps the test ring securely against the socket shoulder. Tell us the notch count that works.
If all holes are too small or too large, report that rather than forcing a fit.
This gauge does not validate the final bracket, heat behavior or cord restraint.

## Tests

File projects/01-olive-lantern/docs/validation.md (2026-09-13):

# Validation record

Original sections generated September 12, 2026; cap added and all meshes
regenerated and checked September 13, 2026.

- All six binary STLs have the expected record lengths.
- All six generated meshes have nondegenerate triangles, closed manifold
  edges, consistent winding, positive volume, and dimensions below the P2S's
  nominal 256 mm limits. Detailed output: `mesh-report.json`.
- Full-size parts: 243.6 × 243.6 × 216 mm base and middle; top height 210 mm.
- Default assembly: one base, five middles, one top; 1470 mm tall with seated
  shoulders. Modeled material volume: 1303.3 cm³ before slicer adjustments.
- Separate cap: Ø224 × 9.2 mm, printed face-down and flipped for assembly;
  seated assembly height 1473.2 mm. Its collar has 0.35 mm radial clearance
  at the receiving rim and 6 mm engagement. The Ø60 mm vent remains open.
  The cap has not been slicer- or physically validated; its intended print
  orientation places the full annular roof on the bed and needs no roof bridge.
- Base geometry was sliced by the installed Bambu Studio 2.8.2.61 CLI with
  resolved P2S 0.4 mm and PETG Translucent profiles, 0.20 mm layers, 3 walls,
  zero sparse infill, Arachne, a 3 mm outer brim, and 40 mm/s outer walls.
  It returned success and produced layer statistics. Fuzzy skin was off for
  this geometry trial; the documented height masking remains a GUI setup step.
- The CLI emitted `Invalid T command (T65535)` while processing the machine
  profile. Consequently this is not a qualified machine-code export, and no
  G-code is supplied. Slice the STLs in the GUI with your selected machine and
  filament profile and inspect the preview before printing.
- No physical print, thermal, stability, or lamp fit validation has been done.
  The short rings and then the base are the intended first physical trials.

The initial CLI attempt loaded unresolved inherited profiles, defaulted to a
200 mm bed, and rejected placement. A second run resolved the installed profile
inheritance and used the correct 256 mm bed. The original failure was a CLI
profile-loading problem, not a mesh-size result.

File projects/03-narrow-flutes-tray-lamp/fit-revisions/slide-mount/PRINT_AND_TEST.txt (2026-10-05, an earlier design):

Slide mount mechanical trial — no metal bolts

Print slide_receiver_test_PETG.3mf flat in PETG at 100% scale using the same profile as the accepted bracket. The 0.35 mm side and 0.45 mm vertical clearances are trials. Inspect the short inward rail lips in Bambu Studio; if supports are needed, restrict them to the lips and remove them fully. Keep the lateral spring relief clear. This is a single connected receiver with an integral flexible tab, not a preassembled moving mechanism. Successful support-free printing is not yet verified.

Print TWO copies of anchor_snap_pin_PETG_print_two.3mf, round head on the bed, in PETG at 100% scale. Inspect split shaft and hook tips; use fine layers (e.g. 0.16 mm) and avoid supports inside the split. Pins are deliberately separate replaceable parts.

Keep the socket unplugged. Start with bracket alone, cord anchor loose and bulb removed. The receiver's closed end is the back stop. Insert bracket from the opposite open end, upright socket plate leading, with its broad base between the two rails. Press the small latch tab outward, away from the rail channel, and slide gently to the back stop; release the tab. The tooth should spring in just beyond the bracket's trailing base edge. Do not force or sand before reporting a binding fit.

Check upward capture by gently lifting the bracket; rail lips should prevent lift-out. Check sideways rocking and gently pull toward the entry; the latch should prevent sliding out. Push the tab outward to release and slide back out. Perform several cycles and inspect for cracks, permanent bending or layer separation. Do not energize this trial assembly.

After the rail fit works, put the existing T-shaped cord anchor on the bracket with round holes aligned at X +/-20,Y+12 and tongue toward +Y. The receiver's pin holes line up only when the bracket is fully seated. Push one printed pin down each anchor hole through anchor, bracket base and receiver floor. Lift the fixture off the table to give hooks room to emerge. Push gently; stop if resistance is high or hooks crack. Check that heads retain the anchor and hooks emerge underneath. Some axial clearance is intentional; report wobble/slipping. To remove, squeeze the two split tips together from underneath and push up. Do not use pliers on the cord or electrical parts.

Reinstall socket and bulb, reconnect cord tie with slack and no insulation compression. A gentle mechanical cord check requires holding the receiver securely. These test parts are not a final electrical/heat-qualified fixture.

Report: (1) slides easily or binds; (2) latch clicks/retains/releases; (3) rail lift/rocking; (4) both pins fit and hold the anchor; (5) photos seated and underneath. Once accepted, receiver will be integrated into lamp. Do not print the old bolted lamp body for this mounting option.

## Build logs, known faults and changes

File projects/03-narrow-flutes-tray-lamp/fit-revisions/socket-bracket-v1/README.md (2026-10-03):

# Socket bracket V1

Print [socket_bracket_40mm_PETG.3mf](../../models/socket_bracket_40mm_PETG.3mf). This is a standard geometry-only 3MF with millimeter units, not a configured Bambu Studio project. Choose the P2S printer, PETG filament and supports in Bambu Studio; slice and inspect before printing. Archive/XML and round-trip geometry checks passed; Bambu Studio import has not been tested.

The bracket uses the physically accepted 40 mm bore and 3 mm clamping plate. Complete bracket fit is pending. The modeled bracket, provisional socket shape and bulb clear the existing lamp body; the socket shape remains photo-based. Cord restraint and thermal validation are unfinished. Test unplugged before printing the lamp body.

See [print and fit instructions](PRINT_AND_FIT.txt), [validation](validation.json), and [CAD preview](bracket-preview.png). The [generator](generate.py) writes STL, validation, instructions and preview beside itself. The committed 3MF carries the same mesh as the STL.

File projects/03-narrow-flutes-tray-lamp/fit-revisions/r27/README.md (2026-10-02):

# R27 corner fit trial

Print [tray_corner_coupon_R27.stl](../../models/tray_corner_coupon_R27.stl) flat in PETG using the same settings as the original coupon. This replaces the original corner coupon for the next fit check.

Photos suggested an approximately 4–6 mm corner gap; this was a visual estimate, not a precise measurement. The trial changes the assumed tray corner radius from 15 to 27 mm (pocket radius 27.6 mm), reducing the nominal diagonal opening by 4.97 mm. Straight-side clearance remains 0.6 mm per side. The original exterior and 80 × 80 × 10 mm coupon envelope are retained.

The exported STL is watertight, consistently wound, and one connected solid. Physical fit is pending. The full test rim and lamp have not been updated to this trial radius; confirm this coupon before propagating the change.

Regenerate with the project's dependencies installed: `python generate_coupon.py`. Outputs are written beside this script.

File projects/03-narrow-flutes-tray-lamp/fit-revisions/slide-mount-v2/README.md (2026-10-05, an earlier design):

# Slide receiver V2 — corrected insertion clearance

Print only [slide_receiver_test_v2_PETG.3mf](../../models/slide_receiver_test_v2_PETG.3mf), flat in PETG at 100% scale. Reuse existing bracket, anchor and pins. Geometry-only 3MF: choose printer/material/support settings in Bambu Studio; inspect the rail lips before printing.

V1 was blocked by the upright plate: the guide lips overlapped its insertion path, and the tooth extended slightly above the bracket base. V2 moves the lips outward to provide 0.35 mm nominal clearance to the 52 mm upright and lowers the tooth to 7.5 mm, below the upright's 8 mm assembled starting height. Rail overlap over the base is now 0.65 mm; lift retention must be physically tested.

Full bracket rigid-guide insertion checks passed at 91 positions, with the flexible latch area excluded to represent manual release. Seated full-bracket overlap is zero. These are geometric checks, not a simulated flexible latch, slicer test or physical fit confirmation.

Follow the [original fit procedure](../slide-mount/PRINT_AND_TEST.txt): slide upright plate first, hold latch outward, seat at closed stop and release. Check sliding, locking, release and lift-out retention before adding anchor/pins. Stop if anything binds. Keep unplugged. Full lamp integration remains pending acceptance.

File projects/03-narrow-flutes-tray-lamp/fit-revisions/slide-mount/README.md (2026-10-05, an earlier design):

# Bolt-free slide mount trial

Print one [receiver](../../models/slide_receiver_test_PETG.3mf) and two [snap pins](../../models/anchor_snap_pin_PETG_print_two.3mf) in PETG at 100% scale. These are geometry-only 3MF files; printer settings and supports are not included. Inspect rail lips in Bambu Studio.

Reuse the existing socket bracket and cord anchor. Rails capture the bracket base; an integral lateral spring tab prevents withdrawal. Two separately printed snap pins secure the cord anchor through its existing holes. The receiver is one connected print; it is not a preassembled moving mechanism. Supports may be needed at rail lips.

Follow [print and test instructions](PRINT_AND_TEST.txt) and [diagram](slide-mount-diagram.png). Geometry checks passed. Physical sliding clearance, latch retention, pin fit and durability are pending. The receiver has not been integrated into the full lamp yet. Do not print the old bolted body for this option until the test is accepted and the body is updated. Test unplugged.

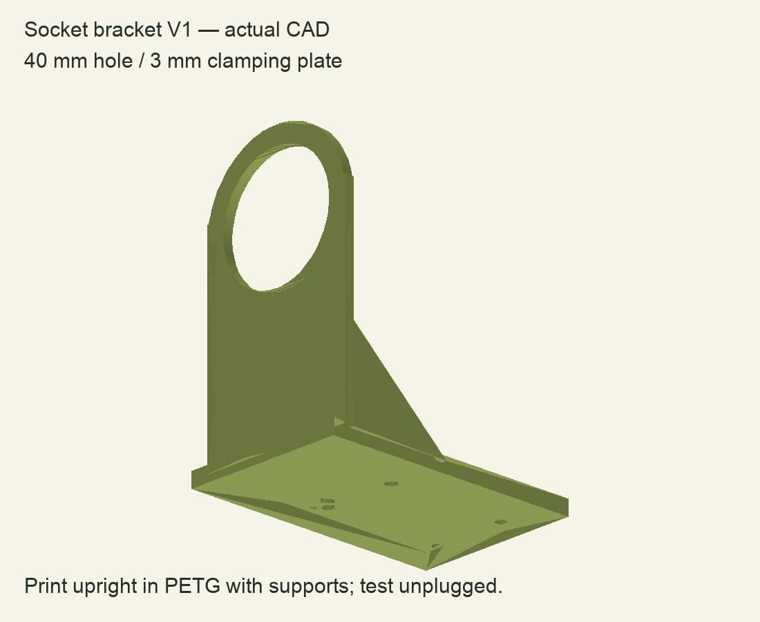
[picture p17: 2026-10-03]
projects/03-narrow-flutes-tray-lamp/fit-revisions/socket-bracket-v1/bracket-preview.png

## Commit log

2026-09-13 Add Olive Lantern shade project with printable parts and fit rings
    [base.stl, cap.stl, fit_female.stl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]
2026-09-15 Add Soft Spiral generator, vented cap, and local full-set build
    [TriLamp_Soft_Spiral_Cap_P2S.3mf, cap.stl]
2026-09-16 Add bowed Organic Lantern shade generator and rounded cap
    [TriLamp_Organic_Lantern_Cap_P2S.3mf, cap.stl]
2026-10-02 Add Narrow Flutes tray lamp V2 prototype
    [olive_body_one_piece_PETG.stl, tan_base_trim_PLA.stl, tan_top_trim_PLA.stl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]
2026-10-02 Add R27 tray corner fit trial
    [tray_corner_coupon_R27.stl]
2026-10-02 Apply accepted R27 corner fit to tray rim and lamp receiver
    [olive_body_one_piece_PETG.stl, tray_corner_coupon.stl, tray_fit_test_rim.stl]
2026-10-03 Add socket fit gauge and record accepted tray fit
    [socket_hole_fit_gauge_37-41mm.stl]
2026-10-03 Add socket bracket prototype and geometry-only 3MF
    [socket_bracket_40mm_PETG.3mf, socket_bracket_40mm_PETG.stl]
2026-10-04 Add cord anchor prototype and lamp geometry-only 3MF files
    [cord_anchor_plate_PETG.3mf, cord_anchor_plate_PETG.stl, olive_body_one_piece_PETG.3mf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]
2026-10-05 Add bolt-free slide receiver and printed anchor pin fit tests
    [anchor_snap_pin_PETG_print_two.3mf, anchor_snap_pin_PETG_print_two.stl, slide_receiver_test_PETG.3mf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]
2026-10-05 Fix slide receiver upright clearance and latch height
    [slide_receiver_test_v2_PETG.3mf, slide_receiver_test_v2_PETG.stl]
2026-10-07 Add V3 lamp body with integrated slide receiver and assembly instructions
    [olive_body_slide_mount_PETG.3mf, olive_body_slide_mount_PETG.stl]
2026-10-07 Add Bambu project with localized receiver support painting and PETG settings
    [olive_body_slide_mount_PETG_Bambu_project.3mf]
2026-10-27 Add closed-bottom lamp base with corner fit coupon and assembly instructions
